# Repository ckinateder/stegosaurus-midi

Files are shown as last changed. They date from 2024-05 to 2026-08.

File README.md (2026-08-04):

Stegosaurus Logo

# stegosaurus

Stegosaurus is an open-source MIDI controller. The controller is built around the Arduino framework and uses the MIDI protocol to communicate with a computer. It is designed to be easily configurable, with the ability to change the behavior of the controller using SysEx messages. 

TODO:
- [x] Add hardware MIDI support to the Pico
- [x] Add SysEx support to the Pico
- [ ] Web interface for programming
    - [x] Basic interaction
    - [ ] Add SysEx messages
- [ ] EEPROM module
- [ ] Pinouts
## Project Structure

This project is organized as follows:

- [`firmware/`](firmware/): main firmware code
- [`interface/`](interface/): code for the web interface

### Firmware

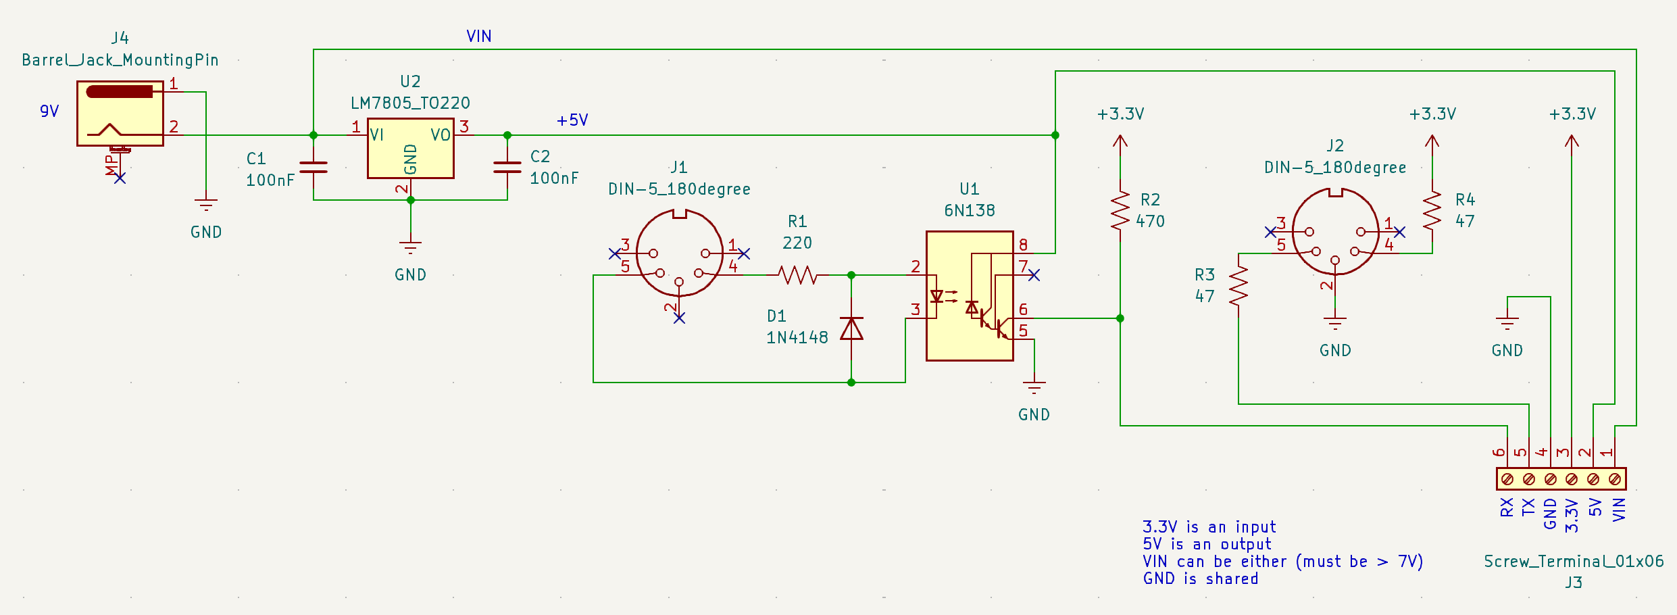
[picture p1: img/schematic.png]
schematic


This project runs on the **Raspberry Pi Pico**.
To set it up in the Arduino IDE, follow [this guide](https://randomnerdtutorials.com/programming-raspberry-pi-pico-w-arduino-ide/). You will probably have to hold down the BOOTSEL button while plugging in the Pico to get it into bootloader mode for the first time. Pay attention to these upload settings:

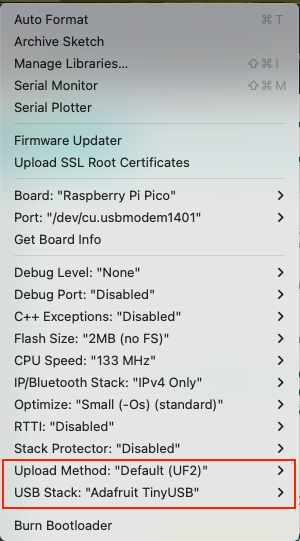
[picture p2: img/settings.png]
upload settings
.

Make sure the selected port matches the port that the Pico is connected to.

Required libraries:

- [EasyButton](https://github.com/evert-arias/EasyButton) (@v2.0.3)
- [Adafruit TinyUSB](https://github.com/adafruit/Adafruit_TinyUSB_Arduino) (@v3.1.4)

## Interface for Programming

See [this page](https://learn.sparkfun.com/tutorials/midi-tutorial/advanced-messages) for a good reference on MIDI messages.

The Stegosaurus will use SysEx messages to change the behavior of the controller. 

The manufacturer ID for the USB MIDI SysEx messages is `0x00 0x53 0x4D`. The `0x00` indicates that the message has a vendor ID, and the `0x53 0x4D` is the ASCII representation of "SM". This is a unique identifier for the Stegosaurus MIDI controller (I think it is unique). So, if you see a message with this ID, it is likely from the Stegosaurus. The rest of the message is the actual data.

To program the controller behavior, the interface will send a SysEx message with the manufacturer ID, followed by the command byte, and then the data. Keep in mind that the SysEx message maximum length is 128 bytes. This is using this [here](https://github.com/FortySevenEffects/arduino_midi_library/wiki/Using-custom-Settings), but I don't think that any of the messages will be even close to that length.

## MIDI Messages

The Stegosaurus will use the following MIDI messages. Keep in mind that the first 4 bytes of the message are specific to the SysEx MIDI protocol. The rest of the message is the actual data. In accordance with standard practice, every SysEx message is concluded with the SysEx end byte `0xF7`.

### Memory Layout
There are 128 presets, each with 17 slots, and 7 bytes per slot. The slots are numbered 1-16, with slot 0 reserved for metadata. The metadata for each preset is as follows:

| Byte | Description |
|---|---|
| 0 | Switch type |
| 1 | Switch values  |

The switch type is a 1-byte value that indicates the type of switch that the preset uses. Each bit from right to left indicates a switch. 0 is a momentary switch, and 1 is a latching switch. For example, `0b10000000` would mean that SWA is LATCHING and the rest are momentary.

The switch values are a 1-byte value that indicates the current state of the switches. Each bit from right to left indicates a switch. 0 is off, and 1 is on. For example, `0b10000000` would mean that SWA is on and the rest are off. This only applies to latching switches. This value is tracked so that the user can set a switch to a specific state when they enter a preset. **Note: There is not currently a way to set this data over the MIDI bus. It must be hard-coded. This will be fixed in the future.**

The rest of the slots are the actual data for the preset. Each slot is 7 bytes long. The data is as follows:

| Byte | Description |
|---|---|
| 0 | Trigger |
| 1 | Action |
| 2 | Switch number  |
| 3 | MIDI channel |
| 4 | Data 1 |
| 5 | Data 2 |
| 6 | Data 3 |

This can be visualized in the following diagram:

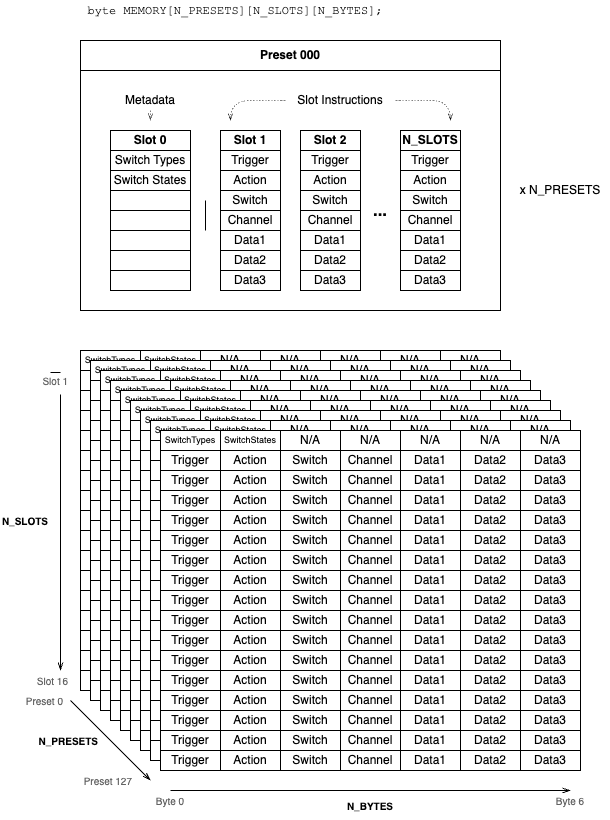
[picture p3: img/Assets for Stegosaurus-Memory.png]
memory layout


### Message Structure

The message is broken up into 2 parts: the header and the data. The header is the first 8 bytes of the message, and the data is the rest of the message.

The Message ID is a 2-byte value that is unique to each message. This is used to ensure that the message is not a duplicate. The message ID is generated by the interface and is incremented for each message. The Stegosaurus will respond with the same message ID in the response message. The message ID is ONLY ever 0 if it's unitialized. Once the maximum value is reached, it will reset to 1. The device itself will never initiate a message, so it will never have to generate a message ID. It will only respond to messages.

#### Header

| Byte | Description | Value |
|---|---|---|
| 0 | Status byte | 0xF0 (SysEx start) |
| 1 | Vendor ID | 0x00 (Three-byte Vendor ID) |
| 2 | Vendor ID | 0x53 (Vendor ID) |
| 3 | Vendor ID | 0x4D (Vendor ID) |
| 4 | Message ID byte 1| Unique ID to ensure proper separation of messages |
| 5 | Message ID byte 2| Unique ID to ensure proper separation of messages |
| 6 | Condition* | 0, 1, or 2|
| 7 | Message type** | See table |

**\*Conditions:**

| Type | Description | Details|
|---|---|-|
| 0 | Request | The interface is requesting an action from the Stegosaurus |
| 1 | ResponseOk | The device is responding to a request w/o error |
| 2 | ResponseError | The device is responding to a request with an error |

**\*\*Message types:**

| Type | Description |
|---|---|
| 0 | Write to a slot |
| 1 | Read from a slot |
| 2 | System parameter set |
| 3 | System parameter get |
| 4 | Get preset |

#### Message Data

The data is the rest of the message. There are 3 types of messages: write to a slot, read from a slot, and system parameter set. Each message has a different format.

#### Write to a Slot

| Byte | Description |
|---|---|
| 5 | Preset to modify |
| 6 | Slot to modify |
| 7 | Trigger  |  
| 8 | Action |
| 9 | Switch number |  
| 10 | MIDI channel |
| 11 | Data 1 |
| 12 | Data 2 |
| 13 | Data 3 |

The trigger, action, and switch number are all 1-byte values. The trigger is what will cause the action to occur. The action is the MIDI message that will be sent. The switch number is the switch that the action will be associated with, if the trigger is a type of press.

| Trigger | Value |
|---|---|
| EnterPreset | 1 |
| ExitPreset | 2 |
| ShortPress | 3 |
| LongPress | 4 |
| DoublePress | 5 |

| Action | Value |
|---|---|
| ControlChange  | 1 |
| ProgramChange  | 2 |
| PresetUp | 3 |
| PresetDown | 4 |

| Switch | Value |
|---|---|
| SWA | 0 |
| SWB | 1 |
| SWC | 2 |
| SWD | 3 |

This message will write the data to the specified preset and slot in memory.

#### Read from a Slot

| Byte | Description |
|---|---|
| 5 | Preset to read |
| 6 | Slot to read |

This returns the data from the specified slot in the specified preset in the same format as the write message.
Note that the preset and slot are returned in the message.

#### System Parameter Set

| Byte | Description |
|---|---|
| 5 | Parameter to set |
| 6 | Value to set |

This sets a system parameter. The parameters are as follows:

| Parameter | Value |
|---|---|
| CurrentPreset  | 0 |

This message will set the specified parameter to the specified value.

#### System Parameter Get

| Byte | Description |
|---|---|
| 5 | Parameter to get |

This gets a system parameter. The parameters are the same as the set message.

#### Get Preset

| Byte | Description |
|---|---|
| 5 | Preset to get |

This returns the data for the specified preset. Note: this will be a long array.

### Example Messages

#### Write to a Slot
#### Read from a Slot
#### System Parameter Set
#### System Parameter Get
#### Get Preset

## Interface

This will have to use WebMIDI to communicate with the Arduino.

A good first step for this is to get a list of MIDI devices. I want to do this in React.

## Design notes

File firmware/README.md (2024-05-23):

# stegosaurus-firmware

## Project Structure

THis project is organized as follows:

- `firmware/`: main firmware code
- `interface/`: code for the web interface

## Requirements

### Firmware

#### Raspberry Pi Pico

This is currently being switched over to work with the Raspberry Pi Pico.
To set it up in the Arduino IDE, follow [this guide](https://randomnerdtutorials.com/programming-raspberry-pi-pico-w-arduino-ide/). You will probably have to hold down the BOOTSEL button while plugging in the Pico to get it into bootloader mode for the first time. Pay attention to these upload settings:

upload settings.

Make sure the selected port matches the port that the Pico is connected to.

Required libraries:

- [EasyButton](https://github.com/evert-arias/EasyButton) (@v2.0.3)
- [Adafruit TinyUSB](https://github.com/adafruit/Adafruit_TinyUSB_Arduino) (@v3.1.4)

https://electronics.stackexchange.com/questions/623026/problem-working-with-midi-on-hardware-serial-port-on-raspberry-pi-pico-2040

### Interface

This will have to use WebMIDI to communicate with the Arduino.

A good first step for this is to get a list of MIDI devices. I want to do this in React.

## Odds and Ends

See [this page](https://learn.sparkfun.com/tutorials/midi-tutorial/advanced-messages) for a good reference on MIDI messages.

The manufacturer ID for the USB MIDI SysEx messages is `0x00 0x53 0x4D`. The `0x00` indicates that the message has a vendor ID, and the `0x53 0x4D` is the ASCII representation of "SM". This is a unique identifier for the Stegosaurus MIDI controller (I think it is unique). So, if you see a message with this ID, it is likely from the Stegosaurus. The rest of the message is the actual data.

To program the controller behavior, the interface will send a SysEx message with the manufacturer ID, followed by the command byte, and then the data. Keep in mind that the SysEx message maximum length is 128 bytes. This is changable [here](https://github.com/FortySevenEffects/arduino_midi_library/wiki/Using-custom-Settings), but I don't think that any of the messages will be even close to that length.

## MIDI Messages

This SysEx message will be used to change the behavior of the controller. 

### Changing Preset Behavior
 
| Byte | Value |
|---|---|
| 0 | Left nybble denotes the operation. 0x0 for modify preset operation. Right nybble denotes whether or not to save to EEPROM or not. 0x0 for no, 0x1 for yes. For example, 0x01 for modify preset and write to EEPROM; 0x00 for modify preset but not write to EEPROM (probably for debugging). |
| 1 | Preset (allow up to 0-127)  |
| 2 | Only using the right nybble. Trigger on enter preset, exit preset, or switch press number (0x0 to 0x03 switch number, 0xE for on preset entry, 0xF for on preset exit). |
| 3 | Storage location for preset (1 byte would allow 256 different locations per byte, but that’s too many - I think up to 64 is the maximum that would make sense) |
| 4 | Message type (cc/pc), channel |
| 5 | Message number |
| 6 | Message value (if needed, for cc message) |

## TRASH

#### Teensy 4.0

[DEPRECATED]

This is currently built on a Teensy 4.0. It should also work with any ATMega32U4 board, such as the Arduino Micro, HOWEVER, the USB name on the Micro will show up as just "Arduino Micro". The firmware is written in C++ and uses the Arduino framework. 
Make sure you have the arduino IDE installed, and the Teensyduino add-on. See the [Teensyduino](https://www.pjrc.com/teensy/td_download.html) page for more information. The following libraries are required:

- [Arduino MIDI Library](https://github.com/FortySevenEffects/arduino_midi_library) (@v5.0.2)
- [Arduino USBMIDI](https://github.com/lathoub/Arduino-USBMIDI) (@v1.1.2)
- [EasyButton](https://github.com/evert-arias/EasyButton) (@v2.0.3)

You'll need to change the USB type to "Serial + MIDI" in the Arduino IDE. This is done by going to `Tools > USB Type` and selecting "Serial + MIDI".

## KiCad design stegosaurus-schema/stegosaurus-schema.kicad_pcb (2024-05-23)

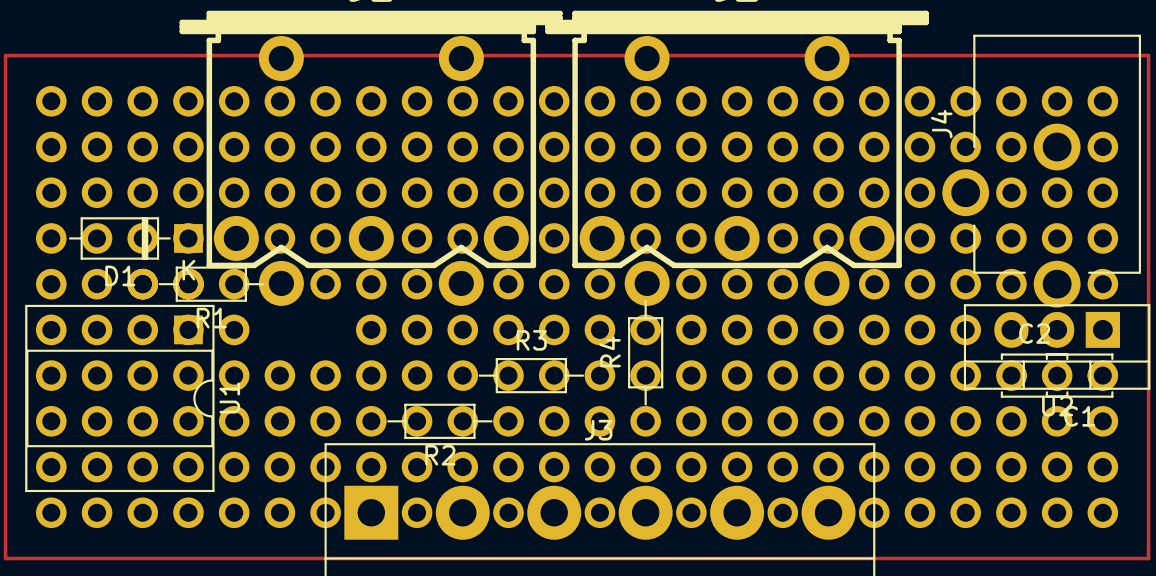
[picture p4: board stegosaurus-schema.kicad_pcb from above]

Board: 2 copper layers, 13 parts (0 on the bottom side), 11 nets, no tracks yet.

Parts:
C1, C2: 100nF; C_Disc_D3.4mm_W2.1mm_P2.50mm
D1: 1N4148; D_DO-35_SOD27_P7.62mm_Horizontal
J1, J2: DIN-5_180degree; MIDI_DIN5
J3: Screw_Terminal_01x06; TerminalBlock_bornier-6_P5.08mm
J4: Barrel_Jack_MountingPin; BarrelJack_CUI_PJ-102AH_Horizontal
R1: 220; R_Axial_DIN0204_L3.6mm_D1.6mm_P7.62mm_Horizontal
R2: 470; R_Axial_DIN0204_L3.6mm_D1.6mm_P7.62mm_Horizontal
R3, R4: 47; R_Axial_DIN0204_L3.6mm_D1.6mm_P7.62mm_Horizontal
U1: 6N138; DIP-8_W7.62mm_Socket
U2: LM7805_TO220; TO-220-3_Vertical

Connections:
+3.3V: J3.4, R2.1, R4.1
GND: C1.2, C2.2, J2.2, J3.3, J4.2, U1.5 (GND), U2.2 (GND)
unnamed: D1.2 (A), J1.5, U1.3 (C2)
unnamed: D1.1 (K), R1.2, U1.2 (C1)
unnamed: J1.4, R1.1
unnamed: J2.4, R4.2
unnamed: J2.5, R3.2
unnamed: J3.1, R2.2, U1.6 (VO2)
unnamed: J3.2, R3.1
unnamed: C2.1, J3.5, U1.8 (VCC), U2.3 (VO)
unnamed: C1.1, J3.6, J4.1, U2.1 (VI)

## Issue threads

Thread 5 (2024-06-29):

Write a button handling library

ckinateder, 2024-06-29:
Needs to handle:
- Combination of buttons
- Short press
- Long press
- Hold (for cycling through)?
- Double tap

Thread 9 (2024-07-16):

Pico crashes after 2 preset changes

ckinateder, 2024-07-16:

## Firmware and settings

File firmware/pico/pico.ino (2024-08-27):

#include <Arduino.h>
#include <Adafruit_TinyUSB.h>
#include <MIDI.h>
#include <EasyButton.h>

// product info
#define VSN "0.1.3"
#define PRODUCT "Stegosaurus"
#define MANUFACTURER "CJK Devices"

// sysex
#define MFID_1 0x53
#define MFID_2 0x4d
#define HEADER_LENGTH 8

// settings
#define SAVE_TO_EEPROM 1
#define MIDICoreUSB_Cable 0 // this corresponds to the virtual "port" or "cable". stick to 0.

// switch press durations
#define SHORT_PRESS_DURATION 100
#define LONG_PRESS_DURATION 750

// button settings
#define PULLUP true
#define DEBOUNCE 40

// Switches
#define NUM_SWITCHES 4
#define SWITCH_1_PIN 10
#define SWITCH_2_PIN 11
#define SWITCH_3_PIN 12
#define SWITCH_4_PIN 13

// LED Builtin
#define LED_PIN 13

// memory settings
#define NUM_PRESETS 128
#define BYTES_PER_SLOT 7
#define SLOTS_PER_PRESET 17

// switch memory location
#define META_SLOT 0
#define SW_TYPE_BYTE 0
#define SW_STATE_BYTE 1

// switch values
#define MOMENTARY 0
#define LATCH 1

// hardcoded midi values
#define ALL_CHANNELS 16
#define NA 0 // switch to 0xFF?

// system values
const byte MFID_ARRAY[3] = {0x00, MFID_1, MFID_2};

/*
ALL BIT LOGIC IS INDEXED FROM LEFT TO RIGHT
*/

// main storage
// first slot may look like [32, 0, ...] - switch type (bit in order) latching, switch state (for latching),
// first slot holds metadata for preset - EXPLORE IN DOCS
byte MEMORY[NUM_PRESETS][SLOTS_PER_PRESET][BYTES_PER_SLOT]; // NUM_PRESETS presets, SLOTS_PER_PRESET slots, bytes each

// the main memory is never modified, only copied from and to
// the current preset memory is modified in real time
// if a preset is loaded, the current preset memory is copied from the main memory
// if a preset is saved, the current preset memory is copied to the main memory
byte CURRENT_PRESET_MEMORY[SLOTS_PER_PRESET][BYTES_PER_SLOT];
byte CURRENT_PRESET = 0;

// keep track of current message
unsigned short CURRENT_MSG_ID = 0; // 2 bytes

// enums
// NONE of these can be 0

/*
  Action type
  8 bits
*/
enum Action
{
  ControlChange = 1,
  ProgramChange = 2,
  PresetUp = 3,   // on stegosaurus
  PresetDown = 4, // on stegosaurus
};

/*
  Trigger type
  4 bits
*/
enum Trigger
{
  EnterPreset = 1,
  ExitPreset = 2,
  ShortPress = 3,
  LongPress = 4,
  DoublePress = 5,
};

/*
  Switch number
  4 bits
*/
// DO NOT CHANGE THESE VALUES. They must climb and start from 0
enum Switch
{
  SWA = 0, // DON'T CHANGE
  SWB = 1, // DON'T CHANGE
  SWC = 2, // DON'T CHANGE
  SWD = 3, // DON'T CHANGE
};

enum MsgTypes
{
  SetSlot = 0,        // set a slot - this will call writeSlot
  GetSlot = 1,        // get a slot - this will call readSlot
  SetSystemParam = 2, // set a system param
  GetSystemParam = 3, // get a system param
  GetPreset = 4,      // get a preset
};

enum SystemParams
{
  CurrentPreset = 0, // the current preset
};

enum Condition
{
  Request = 0,
  ResponseOk = 1,
  ResponseError = 2,
};

// declare defaults
void writeSlot(byte slot, byte trigger, byte action, byte switchNum, byte channel, byte data1 = NA, byte data2 = NA, byte data3 = NA);

// switchs
EasyButton switch1(SWITCH_1_PIN, DEBOUNCE, PULLUP, true);
EasyButton switch2(SWITCH_2_PIN, DEBOUNCE, PULLUP, true);
EasyButton switch3(SWITCH_3_PIN, DEBOUNCE, PULLUP, true);
EasyButton switch4(SWITCH_4_PIN, DEBOUNCE, PULLUP, true);

// bools
bool midiThru = true; // passthrough serial and usb midi

// make a type for all messages
using namespace MIDI_NAMESPACE;
typedef Message<MIDI_NAMESPACE::DefaultSettings::SysExMaxSize> MidiMessage;

// USB MIDI object, with 1 cable
Adafruit_USBD_MIDI USB_MIDI_Transport(1);

// Create a MIDI object with custom settings
// see https://github.com/FortySevenEffects/arduino_midi_library/blob/2d64cc3c2ff85bbee654a7054e36c59694d8d8e4/src/midi_Settings.h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
struct CustomSettings : public midi::DefaultSettings
{
  static const unsigned SysExMaxSize = 256; // Accept SysEx messages up to 256 bytes long.
  static const int BaudRate = 115200;       // Set the baud rate to 31250.
};
MIDI_CREATE_CUSTOM_INSTANCE(Adafruit_USBD_MIDI, USB_MIDI_Transport, MIDICoreUSB, CustomSettings);
MIDI_CREATE_CUSTOM_INSTANCE(HardwareSerial, Serial1, MIDICoreSerial, CustomSettings);

void setup()
{
  // start serial
  Serial.begin(115200);

  // set pins
  pinMode(LED_BUILTIN, OUTPUT);

// Manual begin() is required on core without built-in support for TinyUSB such as mbed rp2040
#if defined(ARDUINO_ARCH_MBED) && defined(ARDUINO_ARCH_RP2040)
  TinyUSB_Device_Init(0);
#endif

  // ------------------- set up connections -------------------
  // set names
  USBDevice.setManufacturerDescriptor(MANUFACTURER);
  USBDevice.setProductDescriptor(PRODUCT);
  USB_MIDI_Transport.setStringDescriptor(PRODUCT);
  // USB_MIDI_Transport.setCableName         (1, "Controller"); // set this if using multiple cable types

  // set handlers
  MIDICoreUSB.setHandleControlChange(onControlChange);
  MIDICoreUSB.setHandleProgramChange(onProgramChange);
  MIDICoreUSB.setHandleSystemExclusive(onSystemExclusive);

  MIDICoreSerial.setHandleControlChange(onControlChange);
  MIDICoreSerial.setHandleProgramChange(onProgramChange);

  // echo all USB messages to devices on the serial
  MIDICoreUSB.setHandleMessage(onMessageUSB);
  MIDICoreSerial.setHandleMessage(onMessageSerial);

  // set to receieve all channels - in configuration, filter them out
  MIDICoreUSB.begin(MIDI_CHANNEL_OMNI);
  MIDICoreSerial.begin(MIDI_CHANNEL_OMNI); // receive on all channels

  // wait until device mounted
  while (!TinyUSBDevice.mounted())
    delay(1);

  // ------------------- set up switchs -------------------
  switch1.onPressedFor(SHORT_PRESS_DURATION, switch1Pressed);
  switch2.onPressedFor(SHORT_PRESS_DURATION, switch2Pressed);
  switch3.onPressedFor(SHORT_PRESS_DURATION, switch3Pressed);
  switch4.onPressedFor(SHORT_PRESS_DURATION, switch4Pressed);

  // begin switchs
  switch1.begin();
  switch2.begin();
  switch3.begin();
  switch4.begin();

  while (!Serial)
    ; // wait for serial port to connect. Needed for native USB

  // ------------------- set up memory -------------------
  // set all memory to 0
  memset(MEMORY, NA, sizeof(MEMORY));

  // populate memory with some defaults
  for (int p = 0; p < NUM_PRESETS; p++)
  {
    // this enables the temporary memory to be used
    setCurrentPreset(p); // set current preset

    // set switch types
    setSwitchType(Switch::SWD, LATCH);
    resetSwitchStates(); // all switches are low

    setSwitchState(Switch::SWD, 1);

    // set midi slots
    writeSlot(1, Trigger::ShortPress, Action::PresetDown, Switch::SWA, NA, NA, NA, NA);    // stego preset
    writeSlot(2, Trigger::ShortPress, Action::PresetUp, Switch::SWB, NA, NA, NA, NA);      // stego preset
    writeSlot(3, Trigger::EnterPreset, Action::ProgramChange, NA, 15, p, NA, NA);          // hx preset
    writeSlot(4, Trigger::ShortPress, Action::ControlChange, Switch::SWC, 15, 69, 8, NA);  // hx snapshot down
    writeSlot(5, Trigger::ShortPress, Action::ControlChange, Switch::SWD, 15, 74, 127, 0); // latch test
    savePreset(p);
  }
  loadPreset(CURRENT_PRESET);
  printPreset(CURRENT_PRESET);
}

void loop()
{
  // -- listen and read
  MIDICoreUSB.read();
  MIDICoreSerial.read();

  // -- any switch logic can go here --
  switch1.read();
  switch2.read();
  switch3.read();
  switch4.read();
}

// -- switch handlers --
void switch1Pressed()
{
  xprintf("[SWA] pressed\n");
  executeSwitchAction(Trigger::ShortPress, Switch::SWA);
}

void switch2Pressed()
{
  xprintf("[SWB] pressed\n");
  executeSwitchAction(Trigger::ShortPress, Switch::SWB);
}

void switch3Pressed()
{
  xprintf("[SWC] pressed\n");
  executeSwitchAction(Trigger::ShortPress, Switch::SWC);
}

void switch4Pressed()
{
  xprintf("[SWD] pressed\n");
  executeSwitchAction(Trigger::ShortPress, Switch::SWD);
}

/**
 * @brief Execute a switch action given a trigger and switch number
 *
 * @param trigger
 * @param switchNum
 */
void executeSwitchAction(Trigger trigger, byte switchNum)
{
  if (getSwitchType(switchNum) == LATCH)
  {
    bool currentState = getSwitchState(switchNum);
    xprintf("Switch %d is %s\n", switchNum, currentState ? "HIGH" : "LOW");
    setSwitchState(switchNum, !currentState);
    bool newState = getSwitchState(switchNum);
    xprintf("Switch %d is now %s\n", switchNum, newState ? "HIGH" : "LOW");
  }
  // xprintf("Switch %d is %s\n", switchNum, getSwitchState( switchNum) ? "HIGH" : "LOW");

  // iterate over slots, skipping slot 0
  for (int i = 1; i < SLOTS_PER_PRESET; i++)
  {
    // read the preset
    byte slotTrigger, action, slotSwitchNum, channel, data1, data2, data3;
    readSlot(i, &slotTrigger, &action, &slotSwitchNum, &channel, &data1, &data2, &data3);

    // check if type is latch
    if (slotTrigger == trigger && slotSwitchNum == switchNum)
      if (getSwitchType(switchNum) == LATCH)
      {
        // check switch state and execute
        if (getSwitchState(switchNum) == 0)
          executeAction(action, channel, data1, data2); // data2 is the value to latch to
        else
          executeAction(action, channel, data1, data3); // data3 is the value to return to
      }
      // if momentary, just execute
      else
        executeAction(action, channel, data1, data2);
  }
}

/**
 * @brief On receiving control change message
 *
 * @param channel
 * @param number
 * @param value
 */
void onControlChange(byte channel, byte number, byte value)
{
  xprintf("IN: CC: CH %d, CC %d, VAL %d\n", channel, number, value);
}

/**
 * @brief On receiving program change message
 *
 * @param channel
 * @param number
 */
void onProgramChange(byte channel, byte number)
{
  xprintf("IN: PC: CH %d, PC %d\n", channel, number);
}

/**
 * @brief on receiving a message from USB
 *
 * @param message
 */
void onMessageUSB(const MidiMessage &message)
{
  // xprintf("USB: ");
  // printHexArray(message, message.length);
  if (midiThru)
    MIDICoreSerial.send(message);
}

/**
 * @brief on receiving a message from serial
 *
 * @param message
 */
void onMessageSerial(const MidiMessage &message)
{
  // xprintf("Serial: ");
  // printHexArray(message.data(), message.length());
  if (midiThru)
    MIDICoreSerial.send(message);
}

/**
 * @brief Send a control change message
 *
 * @param channel
 * @param number
 * @param value
 */
void sendControlChange(byte channel, byte number, byte value)
{
  xprintf("OUT: ControlChange: CH %d, CC %d, VAL %d\n", channel, number, value);
  MIDICoreUSB.sendControlChange(number, value, channel);
  MIDICoreSerial.sendControlChange(number, value, channel);
}

/**
 * @brief Send a program change message
 *
 * @param channel
 * @param number
 */
void sendProgramChange(byte channel, byte number)
{
  xprintf("OUT: ProgramChange: CH %d, PC %d\n", channel, number);
  MIDICoreUSB.sendProgramChange(number, channel);
  MIDICoreSerial.sendProgramChange(number, channel);
}

// -- message creation

/**
 * @brief Write a slot to the current preset memory
 *  The first slot is reserved for metadata.
 * @param slot
 * @param trigger
 * @param action
 * @param switchNum
 * @param channel
 * @param data1
 * @param data2
 * @param data3
 */
void writeSlot(byte slot, byte trigger, byte action, byte switchNum, byte channel, byte data1, byte data2, byte data3)
{
  // validation
  if (slot == META_SLOT)
  {
    xprintf("Slot %d is reserved for preset metadata!\n", slot);
    return;
  }
  if (slot >= SLOTS_PER_PRESET)
  {
    xprintf("Slot %d is out of bounds!\n", slot);
    return;
  }
  if (channel > ALL_CHANNELS)
  {
    xprintf("Channel %d is out of bounds!\n", channel);
    return;
  }
  if (switchNum >= NUM_SWITCHES)
  {
    xprintf("Switch %d is out of bounds!\n", switchNum);
    return;
  }
  if (data1 > 127 || data2 > 127 || data3 > 127)
  {
    xprintf("Data is out of bounds!\n");
    return;
  }

  // write to memory
  CURRENT_PRESET_MEMORY[slot][0] = trigger;
  CURRENT_PRESET_MEMORY[slot][1] = action;
  CURRENT_PRESET_MEMORY[slot][2] = switchNum;
  CURRENT_PRESET_MEMORY[slot][3] = channel;
  CURRENT_PRESET_MEMORY[slot][4] = data1;
  CURRENT_PRESET_MEMORY[slot][5] = data2;
  CURRENT_PRESET_MEMORY[slot][6] = data3;
}

/**
 * @brief Set the Switch Types
 * Set the switch states for a preset
 * This is encoded as a byte, with each bit representing a switch type.
 * 0 = momentary, 1 = latch. This is enoded from LEFT to RIGHT, so SWA is the leftmost bit.
 * For example, 0b00100000 would mean that SWC is a latch switch, and the rest are momentary.
 * @param types
 */
void setSwitchTypes(byte types)
{
  CURRENT_PRESET_MEMORY[META_SLOT][SW_TYPE_BYTE] = types; // first byte of first slot is switch types
}

/**
 * @brief Get the Switch Types
 * See the setSwitchTypes function for more information
 * @return byte
 */
byte getSwitchTypes()
{
  return CURRENT_PRESET_MEMORY[META_SLOT][SW_TYPE_BYTE];
}

/*
This is encoded as a byte, with each bit representing a switch state.
It's encoded from LEFT to RIGHT, so SWA is the leftmost bit.
For example, 0b10000000 would mean that SWA is HIGH.
This is only used for latch switches, momentary switches are always LOW in this byte.
*/

/**
 * @brief Set the Switch States byte
 * This is encoded as a byte, with each bit representing a switch state.
 * It's encoded from LEFT to RIGHT, so SWA is the leftmost bit.
 * For example, 0b10000000 would mean that SWA is HIGH.
 * This is only used for latch switches, momentary switches are always LOW in this byte.
 * @param states
 */
void setSwitchStates(byte states)
{
  // check validity of data against switch types
  byte types = CURRENT_PRESET_MEMORY[META_SLOT][SW_TYPE_BYTE];
  // if a bit at position i is 1, then the switch at position i must be a latch switch
  // if that's not the case, then the data is invalid
  for (int i = 0; i < 8; i++)
    if (isBitSet(states, i) && !isBitSet(types, i))
    {
      xprintf("Switch state data is invalid!\n");
      return;
    }
  CURRENT_PRESET_MEMORY[META_SLOT][SW_STATE_BYTE] = states; // second byte of first slot is switch states
}

/**
 * @brief Get the Switch States byte
 * This is encoded as a byte, with each bit representing a switch state.
 * It's encoded from LEFT to RIGHT, so SWA is the leftmost bit.
 * For example, 0b10000000 would mean that SWA is HIGH.
 * This is only used for latch switches, momentary switches are always LOW in this byte.
 * @return byte
 */
byte getSwitchStates()
{
  return CURRENT_PRESET_MEMORY[META_SLOT][SW_STATE_BYTE];
}

/**
 * @brief Set the Switch Type object
 * Update a single switch tyoe for a preset
 * Example: setSwitchType(0, Switch:SWA, LATCH) would set SWA to latch.
 * @param switchNum
 * @param type
 */
void setSwitchType(byte switchNum, byte type)
{
  setBit(CURRENT_PRESET_MEMORY[META_SLOT][SW_TYPE_BYTE], switchNum, type);
}

/**
 * @brief Get the Switch Type for a specific switch in a preset
 * Example: getSwitchType(0, Switch::SWA) would return LATCH if SWA is a latch switch.
 * @param switchNum
 * @return byte
 */
byte getSwitchType(byte switchNum)
{
  return isBitSet(CURRENT_PRESET_MEMORY[META_SLOT][SW_TYPE_BYTE], switchNum);
}

/**
 * @brief Set the Switch State object
 * Example: setSwitchState(0, Switch:SWA, 1) would set SWA to HIGH.
 * @param switchNum
 * @param state
 */
void setSwitchState(byte switchNum, byte state)
{
  setBit(CURRENT_PRESET_MEMORY[META_SLOT][SW_STATE_BYTE], switchNum, state);
}

/**
 * @brief Get the Switch State object
 * Example: getSwitchState(0, Switch::SWA) would return 1 if SWA is HIGH.
 * @param switchNum
 * @return byte
 */
byte getSwitchState(byte switchNum)
{
  return isBitSet(CURRENT_PRESET_MEMORY[0][SW_STATE_BYTE], switchNum);
}

/**
 * @brief Reset all switch states to 0
 *
 */
void resetSwitchStates()
{
  CURRENT_PRESET_MEMORY[META_SLOT][SW_STATE_BYTE] = 0; // second byte of first slot is switch states
}

/**
 * @brief Read a slot from memory
 * This reads from the current preset memory, not the main memory.
 * @param slot
 * @param trigger
 * @param action
 * @param switchNum
 * @param channel
 * @param data1
 * @param data2
 * @param data3
 */
void readSlot(byte slot, byte *trigger, byte *action, byte *switchNum, byte *channel, byte *data1, byte *data2, byte *data3)
{
  *trigger = CURRENT_PRESET_MEMORY[slot][0];
  *action = CURRENT_PRESET_MEMORY[slot][1];
  *switchNum = CURRENT_PRESET_MEMORY[slot][2];
  *channel = CURRENT_PRESET_MEMORY[slot][3];
  *data1 = CURRENT_PRESET_MEMORY[slot][4];
  *data2 = CURRENT_PRESET_MEMORY[slot][5];
  *data3 = CURRENT_PRESET_MEMORY[slot][6];
}

/**
 * @brief Print a slot from memory
 * This reads from the main memory, not the current preset memory.
 * @param preset
 * @param slot
 */
void printSlot(byte preset, byte slot)
{
  byte trigger, action, switchNum, channel, data1, data2, data3;
  readSlotFromMemory(preset, slot, &trigger, &action, &switchNum, &channel, &data1, &data2, &data3);
  xprintf("Preset [%d][%d]: %d %d %d %d %d %d %d %d\n", preset, slot, action, trigger, switchNum, channel, data1, data2, data3);
}

/**
 * @brief Execute an action
 * This is a wrapper for sending midi messages based on the action type in the slot.
 * @param action
 * @param channel
 * @param data1
 * @param data2
 */
void executeAction(byte action, byte channel, byte data1, byte data2)
{
  // apply action
  switch (action)
  {
  case Action::ControlChange:
    sendControlChange(channel, data1, data2);
    break;
  case Action::ProgramChange:
    sendProgramChange(channel, data1);
    break;
  case Action::PresetUp:
    loadPreset(CURRENT_PRESET + 1);
    break;
  case Action::PresetDown:
    loadPreset(CURRENT_PRESET - 1);
    break;
  default:
    break;
  }
}

/**
 * @brief DEPRECATED: Read a preset from memory
 * We don't use this anymore, as we have a current preset memory.
 * @param preset
 * @param data
 */
void readPresetFromMemory(byte preset, byte *data)
{
  for (int i = 0; i < SLOTS_PER_PRESET; i++)
    for (int j = 0; j < BYTES_PER_SLOT; j++)
      data[i * BYTES_PER_SLOT + j] = MEMORY[preset][i][j];
}

/**
 * @brief Copy a preset from main memory into a 2d array
 * This is used to copy a preset from main memory into current preset memory.
 * Data is a 2d array, with the first dimension being the slot, and the second dimension being the byte.
 * @param preset
 * @param data
 */
void copyPresetFromMemory(byte preset, byte data[SLOTS_PER_PRESET][BYTES_PER_SLOT])
{
  // validate
  if (preset > NUM_PRESETS - 1)
  {
    xprintf("Preset OOB!\n");
    return;
  }
  for (int i = 0; i < SLOTS_PER_PRESET; i++)
    for (int j = 0; j < BYTES_PER_SLOT; j++)
      data[i][j] = MEMORY[preset][i][j];
}

/**
 * @brief Set the CURRENT_PRESET state variable and copy the preset from main memory into current preset memory.
 *
 * @param preset
 */
void setCurrentPreset(byte preset)
{
  if (preset > NUM_PRESETS - 1)
  {
    xprintf("Preset OOB!\n");
    return;
  }
  CURRENT_PRESET = preset;
  copyPresetFromMemory(CURRENT_PRESET, CURRENT_PRESET_MEMORY);
}

/**
 * @brief Save the current preset memory to main memory
 * This is memory safe - it only copies over the changed slots to avoid unnecessary writes.
 * @param preset
 */
void savePreset(byte preset)
{
  // check bounds
  if (preset > NUM_PRESETS - 1)
  {
    xprintf("Preset OOB!\n");
    return;
  }

  // copy current preset memory to main memory, ignoring anything unchanged
  for (int i = 0; i < SLOTS_PER_PRESET; i++)
    for (int j = 0; j < BYTES_PER_SLOT; j++)
      if (MEMORY[preset][i][j] != CURRENT_PRESET_MEMORY[i][j])
        MEMORY[preset][i][j] = CURRENT_PRESET_MEMORY[i][j];
}

/**
 * @brief Save the current preset memory to main memory
 *
 */
void savePreset()
{
  savePreset(CURRENT_PRESET);
}

/**
 * @brief Read a slot from memory
 * This reads from the main memory, not the current preset memory.
 * @param preset
 * @param slot
 * @param trigger
 * @param action
 * @param switchNum
 * @param channel
 * @param data1
 * @param data2
 * @param data3
 */
void readSlotFromMemory(byte preset, byte slot, byte *trigger, byte *action, byte *switchNum, byte *channel, byte *data1, byte *data2, byte *data3)
{
  *trigger = MEMORY[preset][slot][0];
  *action = MEMORY[preset][slot][1];
  *switchNum = MEMORY[preset][slot][2];
  *channel = MEMORY[preset][slot][3];
  *data1 = MEMORY[preset][slot][4];
  *data2 = MEMORY[preset][slot][5];
  *data3 = MEMORY[preset][slot][6];
}

/**
 * @brief Load a preset from memory
 * Apply EnterPreset and ExitPreset actions
 * Reset latch switches
 * @param preset
 */
void loadPreset(byte preset)
{
  // savePreset(CURRENT_PRESET); // save current preset

  // check bounds
  if (CURRENT_PRESET == 0 && preset >= NUM_PRESETS - 1)
    preset = NUM_PRESETS - 1;
  else if (preset >= NUM_PRESETS)
    preset = 0;

  // apply ExitPreset actions from CURRENT_PRESET
  for (int i = 1; i < SLOTS_PER_PRESET; i++)
  {
    byte trigger, action, switchNum, channel, data1, data2, data3;
    readSlot(i, &trigger, &action, &switchNum, &channel, &data1, &data2, &data3);
    if (trigger == Trigger::ExitPreset)
      executeAction(action, channel, data1, data2);

    // apply latch off if switch is a latch and on
    if (getSwitchType(switchNum) == LATCH && getSwitchState(switchNum) == 1)
      executeAction(action, channel, data1, data3);
  }

  // copy preset to current preset memory
  setCurrentPreset(preset);

  // load preset and apply EnterPreset actions
  xprintf("Load preset %d\n", preset);
  printPreset(preset);

  // apply EnterPreset actions from CURRENT_PRESET
  for (int i = 1; i < SLOTS_PER_PRESET; i++)
  {
    byte trigger, action, switchNum, channel, data1, data2, data3;
    readSlot(i, &trigger, &action, &switchNum, &channel, &data1, &data2, &data3);
    if (trigger == Trigger::EnterPreset)
      executeAction(action, channel, data1, data2);

    // apply latch on if switch is a latch and ON at start
    if (getSwitchType(switchNum) && getSwitchState(switchNum) == 1)
      executeAction(action, channel, data1, data2);
  }
}
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

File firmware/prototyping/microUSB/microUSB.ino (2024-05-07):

// includes
#include <USB-MIDI.h>
#include <EasyButton.h>
#include <time.h>

#define LED_PIN 13
#define VSN "0.1.0"

#define MFID_1 0x53
#define MFID_2 0x4d

// MIDIUSB Cable
#define MIDICoreUSB_Cable 0 // this corresponds to the virtual "port" or "cable". stick to 0.

// make a type for all messages
using namespace MIDI_NAMESPACE;
typedef Message<MIDI_NAMESPACE::DefaultSettings::SysExMaxSize> MidiMessage;

// create midi instances
MIDI_CREATE_INSTANCE(HardwareSerial, Serial1, MIDICoreSerial);
USBMIDI_CREATE_INSTANCE(MIDICoreUSB_Cable, MIDICoreUSB);

// bools
bool echoUSBtoSerial = true;
bool echoUSBtoUSB = true;

void setup() {
  Serial.begin(9600);
  while(!Serial); // wait for Serial to be ready
  
  // print welcome
  xprintf("Welcome to Stegosaurus v%s!\n", VSN);
  xprintf("Echoing USB messages over Serial: %s.\n", echoUSBtoSerial ? "true" : "false");
  xprintf("Echoing USB messages back over USB (only for debugging!): %s.\n", echoUSBtoUSB ? "true" : "false");

  // setup LED
  pinMode(LED_PIN, OUTPUT);
  digitalWrite(LED_PIN, LOW);  // LED off

  // set handlers
  MIDICoreUSB.setHandleControlChange(onControlChange);
  MIDICoreUSB.setHandleProgramChange(onProgramChange);
  MIDICoreUSB.setHandleSystemExclusive(onSystemExclusive); 

  // echo all USB messages to devices on the serial
  MIDICoreUSB.setHandleMessage(onMessageUSB);

  // set to receieve all channels - in configuration, filter them out
  MIDICoreSerial.begin(MIDI_CHANNEL_OMNI); // receive on all channels
  MIDICoreUSB.begin(MIDI_CHANNEL_OMNI); // receive on all channels
}

void loop() {
  // -- listen and read
  MIDICoreUSB.read();
  MIDICoreSerial.read();

  // -- any button logic can go here --

}

// -- message handlers --
static void onSystemExclusive(byte *data, unsigned int length) {
  // check last byte in msg - if it is F0, then more is coming
  // if it is F7, it is the last
  byte lastBit = *(data + length - 1); // last byte in data

  // assign last bit
  bool last = false;
  if(lastBit == 0xF7)
    last = true;

  // print
  xprintf("SysEx Message (%dB): ", length);
  printBytes(data, length);
  if (last) {
    Serial.println(F(" (end)"));
  } else {
    Serial.println(F(" (tbc)"));
  }

  // exit if not last bit
  if(last && checkVendor(data, length))
    parseSysExMessage(data, length);
  else
    Serial.println(F("Unexplained issue! The SysEx message is not getting processed"));
}

static void parseSysExMessage(byte *data, unsigned int length) {
  
}

static void onControlChange(byte channel, byte number, byte value) {
  xprintf("ControlChange from channel: %d, number: %d, value: %d\n", channel, number, value);
}

static void onProgramChange(byte channel, byte number) {
  xprintf("ProgramChange from channel: %d, number: %d\n", channel, number);
}

// echo all messages over usb
static void onMessageUSB(const MidiMessage& message) {
  if(echoUSBtoSerial){
    //Serial.println("Echoing message from USB to DIN.");
    MIDICoreSerial.send(message);
  }
  if(echoUSBtoUSB){
    MIDICoreUSB.send(message);
  }
  // flashLed();
}

bool checkVendor(const byte *data, unsigned int size) {
  if(size < 5) // if not long enough to contain the needed bytes, then it doesn't match
    return false;
  return ( *(data + 1) == 0x00 && *(data + 2) == MFID_1 && *(data + 3) == MFID_2 );
}

// -- utility 
void printBytes(const byte *data, unsigned int size) {
  while (size > 0) {
    byte b = *data++;
    if (b < 16) Serial.print('0');
    Serial.print(b, HEX);
    if (size > 1) Serial.print(' ');
    size = size - 1;
  }
}

void xprintf(const char *format, ...)
{
  char buffer[256];  // or smaller or static &c.
  va_list args;
  va_start(args, format);
  vsprintf(buffer, format, args);
  va_end(args);
  Serial.print(buffer);
}

void flashLed(){
  digitalWrite(LED_PIN, HIGH);
  delay(100);
  digitalWrite(LED_PIN, LOW);
}

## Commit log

2024-05-04 sysex framework in
2024-05-12 start to use the pico
2024-05-23 start adding schematics
    [stegosaurus-schema.kicad_pcb, stegosaurus-schema.kicad_sch]
2024-06-08 pico works on hardware
2024-06-09 more values
    [stegosaurus-schema.kicad_sch]
2024-06-17 readme and arduino
2024-06-17 add image
    [stegosaurus-schema.kicad_sch]
2024-06-21 pico changes
2024-06-24 sample button config
2024-06-24 switch enum
2024-06-28 about to drop switch type from slots
2024-06-29 progresss, but switches aren't matching
2024-06-30 slots fixed
2024-06-30 change printing
2024-07-13 add get slot
2024-07-13 starting to get slots
2024-07-27 starting to switch to using the message ID
2024-07-28 updated pico to use msg ids and attitudes, interface NOT updated
